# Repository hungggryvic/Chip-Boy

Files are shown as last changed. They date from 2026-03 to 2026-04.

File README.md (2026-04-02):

# Chip-Boy
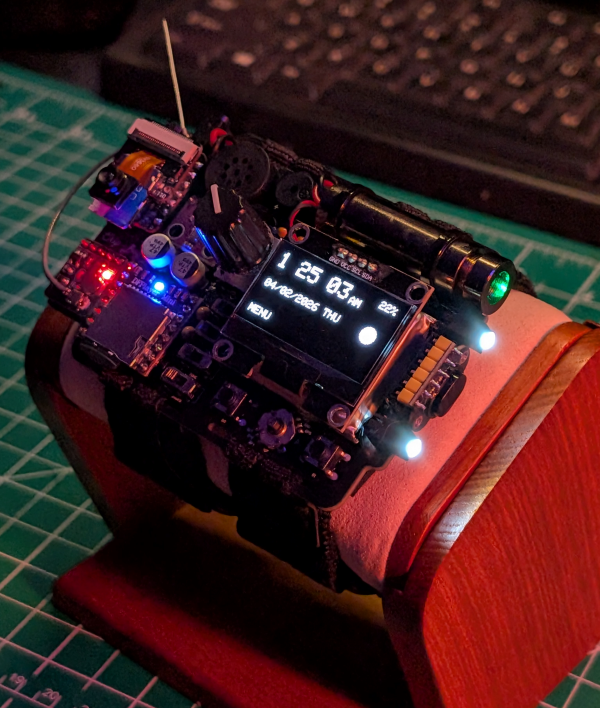
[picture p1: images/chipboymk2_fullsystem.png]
Chip-Boy Mk.2

The Chip-Boy is an ESP32-based smartwatch built on a custom PCB. It is a wrist-mounted device designed as a compact “mini computer,” focused on sensor integration, exploration, and entertainment.

The system integrates multiple sensors, including a BME280 environmental sensor, a time-of-flight distance sensor, and a BNO055 IMU for motion tracking. A 1.3" 128x64 OLED display provides a user interface, allowing navigation through menus and submenus using a combination of buttons and a rotary encoder, all operable with one hand.

The device includes an MP3 player and speaker system using a DFPlayer Mini, which reads audio files from an SD card with custom firmware and track management. It also features three white LEDs for flashlight functionality and a laser module for distance measurement and experimental use.

The ESP32-S3 Sense onboard camera and microphone enable image capture and audio recording, with files stored directly to an SD card. A GPS module provides location tracking with accuracy up to approximately 6 meters, along with automatic time and date synchronization.

Battery voltage is monitored using a voltage divider circuit connected to an ADC pin, allowing estimation of remaining battery life. The system also uses an MCP23008 I2C GPIO expander to manage inputs and control logic efficiently. A small 3V buzzer provides notifications and audio feedback. 

---

## Features

- **OLED Display Interface**  
  1.3" 128x64 OLED display with a custom menu-based UI, allowing users to navigate apps, view data, and interact with the system in real time.

- **Intuitive Input System**  
  Button-controlled navigation combined with a rotary encoder enables one-handed operation and smooth menu traversal.

- **Modular Application System**  
  Supports multiple built-in applications such as clock, navigation, compass, and media player, with the ability to expand functionality through additional modules.

- **Sensor Integration**  
  Combines multiple sensors to provide environmental, motion, and distance data for real-time feedback and analysis.

- **BNO055 IMU (Motion Tracking)**  
  Provides accelerometer, gyroscope, and magnetometer data for orientation tracking, compass functionality, and motion-based applications.

- **BME280 Environmental Sensor**  
  Measures temperature, humidity, and pressure, enabling environmental monitoring.

- **TOF400C Time-of-Flight Sensor**  
  Enables accurate distance measurement for proximity detection and navigation assistance.

- **GPS Module (Positioning & Time Sync)**  
  Provides location tracking with ~6 meter accuracy and automatic time/date calibration.

- **Camera & Microphone (ESP32-S3 Sense)**  
  Captures images and records audio, storing media directly to an SD card.

- **Audio Playback System (DFPlayer Mini)**  
  Plays MP3 files from an SD card through an onboard speaker, with custom firmware handling track selection and playback control.

- **Laser Module**  
  Used for distance indication, targeting, and experimental/measurement applications.

- **Flashlight Functionality**  
  Three high-brightness white LEDs provide illumination for low-light environments.

- **Battery Monitoring System**  
  Voltage divider connected to an ADC pin enables real-time battery level estimation.

- **Expanded I/O Control (MCP23008)**  
  I2C-based GPIO expander increases available input/output pins for buttons and peripherals.

- **Audio Feedback (Buzzer)**  
  Provides system notifications and user feedback through sound cues.

## Hardware

The Chip-Boy is built around a custom-designed embedded hardware platform integrating multiple sensors, peripherals, and user interface components onto a compact wearable PCB.

### Core System

- **ESP32-S3 (Seeed Studio XIAO)**  
  Main microcontroller responsible for system control, application execution, and peripheral interfacing. Provides Wi-Fi/Bluetooth capability, camera support, and sufficient processing power for real-time tasks.

- **Custom PCB (Altium Designer)**  
  Multi-layer board designed to integrate all components into a compact wrist-mounted form factor. Includes power routing, signal management, and modular connector interfaces.

---

### Display & User Interface

- **128×64 OLED Display (I2C)**  
  Primary user interface for rendering menus, applications, sensor data, and graphics.

- **Buttons + Rotary Encoder (via MCP23008 GPIO Expander)**  
  Enables one-handed navigation through menus and applications. The GPIO expander reduces microcontroller pin usage while supporting multiple inputs.

- **Piezo Buzzer**  
  Provides audio feedback for navigation, alerts, and system events.

---

### Sensors & Modules

- **BNO055 IMU (9-DOF)**  
  Provides orientation, acceleration, and heading data for navigation and motion-based features.

- **BME280 Environmental Sensor**  
  Measures temperature, humidity, and pressure for environmental monitoring.

- **VL53L1X Time-of-Flight Distance Sensor**  
  Enables precise distance measurement for proximity sensing and experimental applications.

- **ATGM336H GPS Module**  
  Provides real-time location data, accurate time synchronization, and navigation capabilities (~6m accuracy).

- **ESP32-S3 Camera (Sense Module)**  
  Integrated camera used for image capture and processing.

- **I2S Microphone (ESP32-S3 Sense)**  
  Enables audio recording and real-time signal capture.

---

### Audio System

- **DFPlayer Mini MP3 Module**  
  Handles audio playback from SD card storage independently of the main processor.

- **Speaker Output**  
  Provides audio output for music playback, notifications, and system feedback.

---

### Storage

- **MicroSD Card Interface**  
  Used for storing audio files, recorded data, and captured images.

---

### Power System

- **3.7V 900mAh LiPo Battery**  
  Provides portable power for the wearable device. Runtime varies based on usage. Heavy power consumption (laser, flashlight, music player) can bring the device to it's minimum operating voltage within 2.5 hours or less, while light usage and battery-saving practices can extend runtime up to 12 hours. More testing and calculations will be conducted in the near future for better analysis. 

- **Voltage Divider (ADC Monitoring Circuit)**  
  100k/100k Ohm divider allows the ESP32 to measure battery voltage and estimate remaining charge.

- **Power Switching Circuit**  
  2n7000 Mosfet switching circuit with decoupling and bulk capacitors enables safe control of system power and peripheral activation.

---

### Additional Features

- **Laser Module (MOSFET-Controlled)**  
  Used for distance assistance and experimental functionality.

- **White LEDs (Flashlight Function)**  
  Provide illumination for low-light environments.

---

### Communication Interfaces

- **I2C Bus** → Sensors, OLED display, GPIO expander  
- **SPI Bus** → SD card and high-speed peripherals  
- **UART** → DFPlayer Mini communication  
- **I2S** → Microphone audio input  
- **Camera Interface** → Native ESP32-S3 camera connection  

---

## Schematic
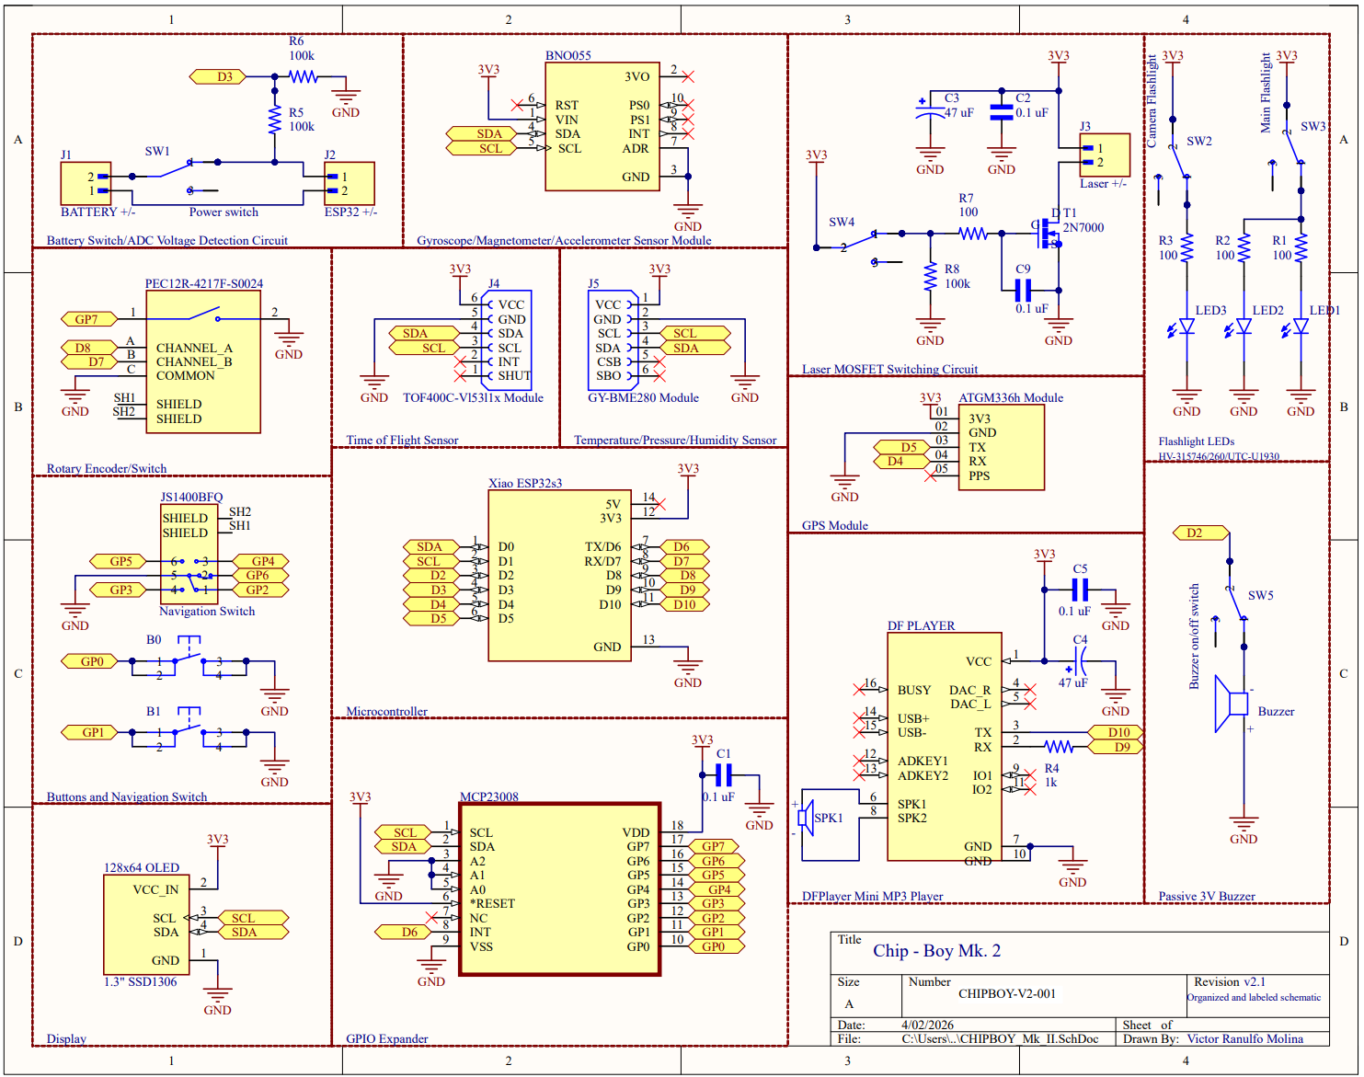
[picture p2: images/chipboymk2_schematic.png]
Chip-Boy Mk.2


## Software

The Chip-Boy firmware is developed in **C++ using the Arduino framework** on the **ESP32-S3 (Seeed Studio XIAO)**. The system is designed as a **modular embedded firmware platform** that functions similarly to a lightweight operating system, managing applications, hardware interfaces, user input, and real-time data processing.

---

### System Architecture

The firmware is structured around a **state-driven application framework**, where each feature is implemented as an independent module (`.cpp/.h` pair). A centralized control loop manages global system states such as:

- Menu navigation
- Active application context
- Display updates (`uiDirty`, `displayReady`)
- Input handling from buttons and rotary encoder

Each application operates within its own state while sharing global resources such as the OLED display, SD card, and audio system.

---

### Application Modules

The system includes multiple fully integrated applications, each with dedicated logic and UI handling:

- **Camera App**  
  Captures images using the ESP32-S3 camera module. Implements a multi-stage pipeline including grayscale frame capture, image scaling to 128×64, thresholding for OLED preview, and saving both bitmap previews and full-resolution JPEGs to SD storage.  

- **Microphone App**  
  Records audio using I2S input at 16 kHz and dynamically constructs WAV files in memory before saving to SD. Includes real-time waveform visualization and recording state management.

- **Navigation App**  
  Provides GPS-based navigation with distance and bearing calculations using the Haversine formula. Includes keypad-based coordinate entry, round-trip tracking, persistent storage using NVS (Preferences), and distance-based adaptive audio feedback. 

- **Location App**  
  Displays real-time time/date and location information with graphical overlays, including a world map rendered directly on the OLED. 

- **Radio App**  
  Manages audio playback using the DFPlayer Mini, including station-based track organization, metadata handling, shuffle functionality, and animated UI elements such as waveform rendering.  

- **Recordings App**  
  Interfaces with stored audio files on the SD card, enabling playback, track navigation, and UI animations synchronized with audio output. 

- **Battery Monitoring App**  
  Continuously samples battery voltage in the background, applies averaging and decimation to maintain long-term history, and renders a time-scaled graph of battery performance. Includes voltage-to-state-of-charge estimation using interpolation. 

---

### User Interface System

- Custom UI rendered using **Adafruit SSD1306 graphics library**
- Hierarchical menu system with app launching and exit handling
- Dynamic redraw control using flags to optimize performance
- Real-time visual elements including:
  - Graphs (battery monitoring)
  - Waveform animations (audio apps)
  - Image previews (camera)
  - Keypad interfaces (navigation input)

---

### Input Handling

- Multi-button input system managed through structured button state tracking
- Rotary encoder support with incremental position tracking
- Debouncing and edge detection for reliable user interaction
- Context-sensitive input handling depending on active application

---

### Communication & Hardware Interfaces

The firmware integrates multiple peripherals using standard embedded communication protocols:

- **I2C** → OLED display, sensors, GPIO expander  
- **SPI / SD interface** → File storage and media access  
- **I2S** → Audio recording (microphone input)  
- **UART** → DFPlayer Mini communication  
- **Camera interface** → ESP32-S3 native camera driver  

---

### Data Management

- SD card used for:
  - Audio recordings and playback
  - Image storage (BMP previews + JPEG files)
- Persistent storage using **ESP32 Preferences (NVS)** for saving navigation data and system states
- Real-time buffering for audio and sensor data processing

---

### Real-Time Operation

The system operates in a continuous loop with:
- Background tasks (battery sampling, sensor updates)
- Event-driven UI updates
- Non-blocking input handling
- Time-based scheduling using `millis()`

---

### Expandability

The firmware is designed for scalability, allowing new applications to be added easily by integrating additional modules into the menu system. Each feature is encapsulated, enabling independent development without modifying core system logic.

---

## How to Run

1. Open the project in Arduino IDE  
2. Select the ESP32-S3 board  
3. Install required libraries
4. Upload the code to the device  

---

## Project Purpose

This project was developed to demonstrate skills in:
- Embedded systems design  
- PCB design and hardware integration  
- Sensor interfacing  
- Real-time system development  

---

## Author

Victor Molina   
Electrical Engineer

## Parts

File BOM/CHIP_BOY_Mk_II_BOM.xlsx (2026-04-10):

Comment | Description | Designator | Footprint | LibRef | Quantity | Website link
1.3" SSD1306 | This is the footprint for a 0.96" oled display with the same pinout. a 1.3" SSD1306 is the the module used in tested demos and what the design is built around, its from Amazon: https://www.amazon.com/dp/B0FL1Q1ZNG?ref=ppx_yo2ov_dt_b_fed_asin_title | 128x64 OLED | MODULE_DM-OLED096-636 | DM-OLED096-636 | 1
ATGM336H | ATGM336H GPS Module GPS & BDS Dual Mode Satellite Positioning Navigator with Antenna Replacement NEO-M8N for Meshtastic GPS Arduino Available on Amazon.com. Any similar module with identical pinout and size will work. https://www.amazon.com/dp/B0DXBHCYN5?ref=ppx_yo2ov_dt_b_fed_asin_title&th=1 | ATGM336h Module | SAMTEC_MTSW-105-07-L-S-240-LL | 5 pin header | 1
SKHHANA010 | 6 x 6 x 5 mm Tactile Momentary Switch button 4 pin. Any similar push button with identical size and pinout will work., [NoValue] | B0, B1 | SW_SKHHANA010 | SKHHANA010 | 2
BNO055 | IMU sensor module by Adafruit industries Part number 2472 | BNO055 | MODULE_2472 | BNO055 | 1
3V Passive Buzzer | 3V passive buzzer two pin through hole 0.36 inch diameter | BZ1 | CUI_CMI-1295IC-0385T | Buzzer_3V | 1
0.1 uF | 0.1 uF ceramic Capacitor through hole | C1, C2, C5, C9 | CAPRB250W50L450T300H550 | 0_1uF100V_CAP_FA14X7R2A104KNU00 | 4
47 uF | EEE-TPV470XAV 47 uF Electrolytic Capacitor surface mount | C3, C4 | CAP_EEETPV470XAV | 47uF_SMD | 2
DFPLAYER | DF Player Mini by DFRobot Part Number DFR0299 | DF PLAYER | MODULE_DFR0299 | DFPLAYER | 1
BATTERY +/- | jumper pins for battery pos/neg wires. | J1 | HARWIN_M20-9990246 | 2_pin_header | 1
ESP32 +/- | jumper pins for esp32s3 pos/neg wires. | J2 | HARWIN_M20-9990246 | 2_pin_header | 1
Laser +/- | Jumper for +/- wires of laser module | J3 | HARWIN_M20-9990246 | 2_pin_header | 1
TOF400C-Vl53l1x Module | TOF400C VL53L1X Time-of-Flight (ToF) Laser Ranging Sensor Breakout 940nm ToF Distance Finder Mini Laser Distance Sensor IIC Output for Ardunio | J4 | SULLINS_PPTC061LFBN-RC | PPTC061LFBNRC | 1
GY-BME280 Module | GY-BME280 Module 6 pin i2c pressure temperature and humidity sensor | J5 | SULLINS_PPTC061LFBN-RC | PPTC061LFBNRC | 1
led_through_hole | through hole indicator LEDs Part Number HV-315746/260/UTC-U1930 | LED1, LED2, LED3 | LED_WP7113ID | led_through_hole | 3
gpio extender | MCP23008-E/P-ND by Microchip Technology GPIO expander | MCP23008 | DIP254P762X533-18 | gpio extender | 1
JS1400BFQ | JS1400BFQ 2 axis + 1 select Navigation Switch | Navigation Switch | SW_JS1400BFQ | nav switch | 1
rotary encoder | PEC12R-4217F-S0024 Rotary encoder with push button | PEC12R-4217F-S0024 | XDCR_PEC12R-4217F-S0024 | rotary encoder | 1
100 | 100 Ohm through hole resistor | R1, R2, R3, R7 | RESAD640W45L370D200 | resistor_through_hole | 4
1k | 1000 Ohm through hole resistor | R4 | RESAD640W45L370D200 | resistor_through_hole | 1
100k | 100k Ohm through hole resistor | R5, R6, R8 | RESAD640W45L370D200 | resistor_through_hole | 3
Power switch | MHSS1104 Top actuated slide switch 300 mA 60V | S1 | SW_MHSS1104 | switch top actuated | 1
Camera Flashlight | MHSS1104 Top actuated slide switch 300 mA 60V | S2 | SW_MHSS1104 | switch top actuated | 1
Main Flashlight | MHSS1104 Top actuated slide switch 300 mA 60V | S3 | SW_MHSS1104 | switch top actuated | 1
Laser switch | MHSS1104 Top actuated slide switch 300 mA 60V | S4 | SW_MHSS1104 | switch top actuated | 1
Buzzer on/off switch | MHSS1104 Top actuated slide switch 300 mA 60V | S5 | SW_MHSS1104 | switch top actuated | 1
CVS-1508 | CVS-1508 Mini 8 ohm 300 mw speaker | SPK1 | SPKR_CVS-1508 | 15mm speaker | 1
2N7000 | 2n7000 n channel 60v 200 mW Mosfet | T1 | TO92 | mosfet | 1
ESP32S3 | Xiao ESP32S3 Sense by Seeed Studio with Camera Module and microphone | Xiao ESP32s3 | MODULE_113991254 | xiao_esp32 | 1

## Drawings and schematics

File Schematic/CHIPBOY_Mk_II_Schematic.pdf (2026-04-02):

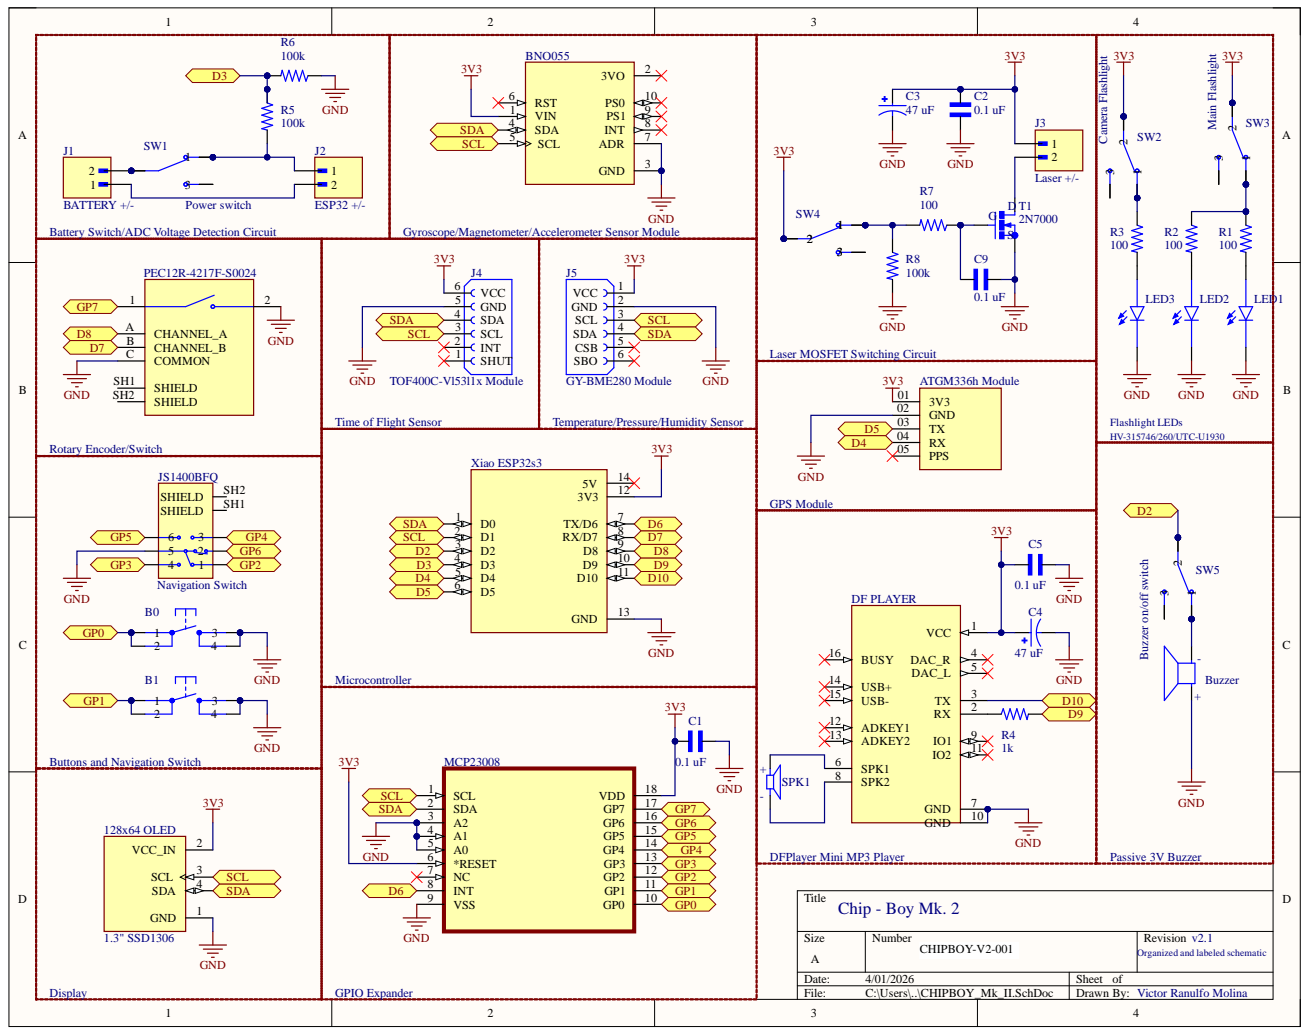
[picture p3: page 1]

Battery Switch/ADC Voltage Detection Circuit

Gyroscope/Magnetometer/Accelerometer Sensor Module

Laser MOSFET Switching Circuit

Buzzer on/off switch

Buttons and Navigation Switch

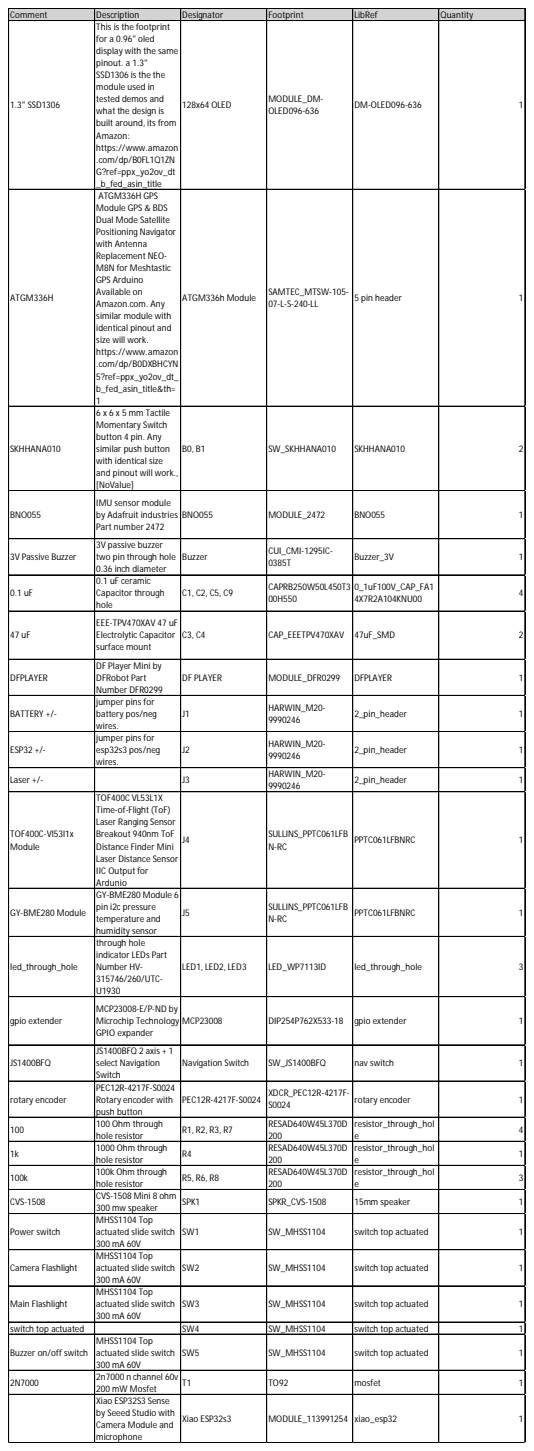
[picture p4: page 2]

Comment | Description | Designator | Footprint | LibRef | Quantity
1.3" SSD1306 | This is the footprint for a 0.96" oled display with the same pinout. a 1.3" SSD1306 is the the module used in tested demos and what the design is built around, its from Amazon: https://www.amazon.com/dp/B0FL1Q1ZNG?ref=ppx_yo2ov_dt_b_fed_asin_title | 128x64 OLED | MODULE_DM-OLED096-636 | DM-OLED096-636 | 1

ATGM336H | ATGM336H GPS Module GPS & BDS Dual Mode Satellite Positioning Navigator with Antenna Replacement NEO-M8N for Meshtastic GPS Arduino Available on Amazon.com. Any similar module with identical pinout and size will work. https://www.amazon.com/dp/B0DXBHCYN5?ref=ppx_yo2ov_dt_b_fed_asin_title&th=1 | ATGM336h Module | SAMTEC_MTSW-105-07-L-S-240-LL | 5 pin header | 1

SKHHANA010 | 6 x 6 x 5 mm Tactile Momentary Switch button 4 pin. Any similar push button with identical size and pinout will work., [NoValue] | B0, B1 | SW_SKHHANA010 | SKHHANA010 | 2

BNO055 | IMU sensor module by Adafruit industries Part number 2472 | BNO055 | MODULE_2472 | BNO055 | 1

3V Passive Buzzer | 3V passive buzzer two pin through hole 0.36 inch diameter | Buzzer | CUI_CMI-1295IC-0385T | Buzzer_3V | 1

0.1 uF | 0.1 uF ceramic Capacitor through hole | C1, C2, C5, C9 | CAPRB250W50L450T3 00H550 | 0_1uF100V_CAP_FA1 4X7R2A104KNU00 | 4

47 uF | EEE-TPV470XAV 47 uF Electrolytic Capacitor surface mount | C3, C4 | CAP_EEETPV470XAV | 47uF_SMD | 2

DFPLAYER | DF Player Mini by DFRobot Part Number DFR0299 | DF PLAYER | MODULE_DFR0299 | DFPLAYER | 1

BATTERY +/- | jumper pins for battery pos/neg wires. | J1 | HARWIN_M20-9990246 | 2_pin_header | 1

ESP32 +/- | jumper pins for esp32s3 pos/neg wires. | J2 | HARWIN_M20-9990246 | 2_pin_header | 1

Laser +/- | | J3 | HARWIN_M20-9990246 | 2_pin_header | 1

TOF400C-Vl53l1x Module | TOF400C VL53L1X Time-of-Flight (ToF) Laser Ranging Sensor Breakout 940nm ToF Distance Finder Mini Laser Distance Sensor IIC Output for Ardunio | J4 | SULLINS_PPTC061LFB N-RC | PPTC061LFBNRC | 1

GY-BME280 Module | GY-BME280 Module 6 pin i2c pressure temperature and humidity sensor | J5 | SULLINS_PPTC061LFB N-RC | PPTC061LFBNRC | 1

led_through_hole | through hole indicator LEDs Part Number HV-315746/260/UTC-U1930 | LED1, LED2, LED3 | LED_WP7113ID | led_through_hole | 3

gpio extender | MCP23008-E/P-ND by Microchip Technology GPIO expander | MCP23008 | DIP254P762X533-18 | gpio extender | 1

JS1400BFQ | JS1400BFQ 2 axis + 1 select Navigation Switch | Navigation Switch | SW_JS1400BFQ | nav switch | 1

rotary encoder | PEC12R-4217F-S0024 Rotary encoder with push button | PEC12R-4217F-S0024 | XDCR_PEC12R-4217F-S0024 | rotary encoder | 1

100 | 100 Ohm through hole resistor | R1, R2, R3, R7 | RESAD640W45L370D 200 | resistor_through_hol e | 4

1k | 1000 Ohm through hole resistor | R4 | RESAD640W45L370D 200 | resistor_through_hol e | 1

100k | 100k Ohm through hole resistor | R5, R6, R8 | RESAD640W45L370D 200 | resistor_through_hol e | 3

CVS-1508 | CVS-1508 Mini 8 ohm 300 mw speaker | SPK1 | SPKR_CVS-1508 | 15mm speaker | 1

Power switch | MHSS1104 Top actuated slide switch 300 mA 60V | SW1 | SW_MHSS1104 | switch top actuated | 1

Camera Flashlight | MHSS1104 Top actuated slide switch 300 mA 60V | SW2 | SW_MHSS1104 | switch top actuated | 1

Main Flashlight | MHSS1104 Top actuated slide switch 300 mA 60V | SW3 | SW_MHSS1104 | switch top actuated | 1

switch top actuated | | SW4 | SW_MHSS1104 | switch top actuated | 1
Buzzer on/off switch | MHSS1104 Top actuated slide switch 300 mA 60V | SW5 | SW_MHSS1104 | switch top actuated | 1

2N7000 | 2n7000 n channel 60v 200 mW Mosfet | T1 | TO92 | mosfet | 1

Xiao ESP32S3 Sense by Seeed Studio with Camera Module and microphone | Xiao ESP32s3 | MODULE_113991254 | xiao_esp32 | 1

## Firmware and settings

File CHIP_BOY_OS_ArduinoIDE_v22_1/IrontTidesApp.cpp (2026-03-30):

// ==============================
// IRON TIDES — CHIP-BOY PORT
// Display: SSD1306 (I2C D0/D1, addr 0x3C)
// Buttons: MCP23008 (BTN1/2/3 + nav switch)
// Pause: Encoder switch (debounced press event)
// ==============================

#include <Arduino.h>
#include <Wire.h>
#include <Adafruit_GFX.h>
#include <Adafruit_SSD1306.h>
#include <math.h>

#ifndef M_PI
#define M_PI 3.14159265358979323846
#endif

// ============================================================================
// WATCH OS APP WRAPPER API
// ============================================================================
static bool s_gameActive = false;
static bool s_setupRan = false;

bool ironTidesIsActive() { return s_gameActive; }
extern void gameExitToMenu();   

// Forward-declare public app API (normally in a header)
void ironTidesEnter();
void ironTidesUpdate();
void ironTidesExit();

// =====================
// Structs
// =====================

struct BtnState {
  uint8_t pin;               // MCP bit index 0..7
  bool lastRead = HIGH;      // HIGH=released (pull-ups)
  bool stable = HIGH;        // debounced stable level
  unsigned long lastChange = 0;
};

struct Ship { float x,y; float dx,dy; bool active; int lives; };

struct Bullet { float x,y; float vx,vy; bool active; bool fromEnemy; };

// =====================
// Forward Declarations
// =====================

// MCP helpers
static bool mcpWriteReg(uint8_t reg, uint8_t val);
static bool mcpReadReg(uint8_t reg, uint8_t &out);
static inline bool mcpReadBit(uint8_t bit);



// Button helpers
static void btnUpdate(BtnState &b);
static inline bool btnDown(const BtnState &b);

// Encoder switch
static bool encSwitchPressedEvent();

// Collision / gameplay helpers
static bool rectsOverlap(float ax,float ay,float aw,float ah,float bx,float by,float bw,float bh);
static bool shipWillCollide(float nx,float ny,float dx,float dy,float ox,float oy,float odx,float ody);
static bool bulletHitsShip(Bullet &b, Ship &s);
static bool bulletHitsBoss(Bullet &b);

// Drawing
static void drawShipOutline(float cx,float cy,float dx,float dy);
static void drawShipFilledArrow(float cx,float cy,float dx,float dy);
static void drawBossShip(float cx,float cy,float dx,float dy);
static void drawFrame();

// Bullets / firing
static void addBullet(float sx,float sy,float vx,float vy,bool fromEnemy);
static void fireLeft(Ship &s,unsigned long &last,bool fromEnemy);
static void fireRight(Ship &s,unsigned long &last,bool fromEnemy);
static void fireTopBurst(Ship &s,unsigned long &last,bool fromEnemy);
static void fireLeftForBoss();
static void fireRightForBoss();
static void fireTopBurstForBoss();

// UI / spawning / reset
static void showCenteredText(const char* msg,int size,int delayTime);
static void spawnEnemyAtRandomBorder(Ship &e);
static void spawnEnemiesForLevel();
static void spawnBossAtRandomBorder();
static void resetGame();

static void drawTitleWaveArches(int xShift);

#include <Arduino.h>
#include <Wire.h>
#include <Adafruit_GFX.h>
#include <Adafruit_SSD1306.h>
#include <math.h>

#ifndef M_PI
#define M_PI 3.14159265358979323846
#endif

// -------- Display ----------
#define SCREEN_WIDTH 128
#define SCREEN_HEIGHT 64
#define OLED_ADDR 0x3C

extern Adafruit_SSD1306 display;


extern bool displayReady;


static bool probeI2C(uint8_t addr) {
  Wire.beginTransmission(addr);
  return Wire.endTransmission() == 0;
}

static void ensureDisplayInit() {
  if (displayReady) return;

  // Only init if the OLED ACKs on I2C
  if (!probeI2C(OLED_ADDR)) return;

  if (display.begin(SSD1306_SWITCHCAPVCC, OLED_ADDR)) {
    displayReady = true;
    display.setTextColor(SSD1306_WHITE);
    display.setTextWrap(false);
    display.clearDisplay();
    display.display();
  }
}


// Rotary encoder switch (pause) — D6 to GND (INPUT_PULLUP)
//#define ENC_SW_PIN D6
// Encoder debouncer vars removed — main loop handles ENC_SW_PIN.


#define ENC_A_PIN D8
#define ENC_B_PIN D7

// Buzzer pin 
#ifndef BUZZER_PIN
#define BUZZER_PIN D2
#endif

// -------- MCP23008 ----------
// And mapping: BTN1->GP0, BTN2->GP6, BTN3->GP1, UP->GP4, DOWN->GP3, RIGHT->GP2, LEFT->GP5

#define MCP_ADDR   0x20
#define MCP_IODIR  0x00
#define MCP_GPIO   0x09
#define MCP_GPPU   0x06

static uint8_t g_mcp_gpio = 0xFF;
static bool g_mcp_ok = false;

static bool mcpWriteReg(uint8_t reg, uint8_t val) {
  Wire.beginTransmission(MCP_ADDR);
  Wire.write(reg);
  Wire.write(val);
  return Wire.endTransmission() == 0;
}

static bool mcpReadReg(uint8_t reg, uint8_t &out) {
  Wire.beginTransmission(MCP_ADDR);
  Wire.write(reg);
  if (Wire.endTransmission(false) != 0) return false;
  if (Wire.requestFrom((int)MCP_ADDR, 1) != 1) return false;
  out = Wire.read();
  return true;
}

//Button debounce struct 

static const unsigned long BTN_DEBOUNCE_MS = 25;

static inline bool mcpReadBit(uint8_t bit) {
  // MCP pull-ups => released=1, pressed=0
  return (g_mcp_gpio & (1u << bit)) ? HIGH : LOW;
}

static void btnUpdate(BtnState &b) {
  bool r = mcpReadBit(b.pin);
  if (r != b.lastRead) {
    b.lastRead = r;
    b.lastChange = millis();
  }
  if ((millis() - b.lastChange) >= BTN_DEBOUNCE_MS) {
    b.stable = b.lastRead;
  }
}

static inline bool btnDown(const BtnState &b) {
  return (b.stable == LOW);
}

// Encoder switch: one true event per debounced press (falling edge)
// encSwitchPressedEvent() removed — pause driven by g_gamePauseRequest.

// Button instances (MCP bits)
static BtnState b1     { .pin = 0 }; // BTN1 -> GP0
static BtnState b2     { .pin = 6 }; // BTN2 -> GP6
static BtnState b3     { .pin = 1 }; // BTN3 -> GP1
static BtnState bUp    { .pin = 4 }; // UP -> GP4
static BtnState bDown  { .pin = 3 }; // DOWN -> GP3
static BtnState bRight { .pin = 2 }; // RIGHT -> GP2
static BtnState bLeft  { .pin = 5 }; // LEFT -> GP5

// ============================================================================
// GAME CODE 
// ============================================================================


Ship enemies[3];
Ship player;
float speed = 0.35;


#define MAX_BULLETS 60
Bullet bullets[MAX_BULLETS];

int playerLives;
int enemiesDefeated = 0;
int totalEnemiesThisLevel = 3;
int currentLevel = 1;
bool gameOver = false;
bool playerWon = false;
int enemiesSpawnedThisLevel = 0;

unsigned long lastFireLeft = 0;
unsigned long lastFireRight = 0;
unsigned long lastFireTop = 0;
const unsigned long fireCooldown = 750;
const unsigned long fireCooldownTop = 750;

unsigned long enemyLastFireLeft[3] = {0,0,0};
unsigned long enemyLastFireRight[3] = {0,0,0};
unsigned long enemyLastFireTop[3] = {0,0,0};
const unsigned long enemyFireCooldown = 1500;
const unsigned long enemyFireCooldownTop = 3000;

bool paused = false;
static bool pauseOverlayDrawn = false;
static unsigned long pauseIgnoreUntilMs = 0;
static bool pauseNeedsRelease = false;

bool enemyDisintegrating = false;
int disintegratingEnemyIndex = -1;
unsigned long disintegrateStart = 0;
const unsigned long disintegrateDuration = 1000;
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

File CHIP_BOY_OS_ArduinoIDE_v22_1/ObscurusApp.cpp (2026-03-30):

// ============================================================
//  OBSCURUS — CHIP-BOY (WatchOS App Module)
//  Display: SSD1306 (I2C D0/D1, addr 0x3C)
//  Buttons: MCP23008 (BTN1/2/3 + nav switch)
//  Pause:   Encoder
//
//  Controls in game:
//    BTN2  (GP6) = JUMP (double jump)
//    BTN1  (GP0) = ATTACK / SHOOT
//    BTN3  (GP1) = CAST SPELL (once learned)
//    DOWN  (GP4) = switch to bow/switch to sword
//    LEFT  (GP2) = move left
//    RIGHT (GP5) = move right
//    ENC SW      = PAUSE
//
//  Pause menu:
//    BTN1 = PLAY (resume)
//    BTN3 = EXIT (back to games menu)
// ============================================================

#include "ObscurusApp.h"
#include <Arduino.h>
#include <Wire.h>
#include <Adafruit_GFX.h>
#include <Adafruit_SSD1306.h>
#include <math.h>

// ============================================================================
// OS APP WRAPPER STATE
// ============================================================================
static bool ob_active   = false;
static bool ob_setupRan = false;
static bool ob_inProgress = false;  // true while a game session is live (survives exit-to-menu)

bool obscurusIsActive() { return ob_active; }

extern void gameExitToMenu();
static void ob_initBoss();
static void ob_checkArrowHitBoss(int i);
static void ob_bossDeathSequence();
static void ob_shakeRoom(int steps);
static void ob_drawPlayer();
static void ob_drawSprite14(const uint8_t src[14][14], int ox, int oy, bool mirror, uint16_t color);
static void ob_drawSprite7(const uint8_t src[7][7], int ox, int oy, bool mirror, uint16_t color, bool flipV = false);
static void ob_drawRoom();
static void ob_drawTurret();
static void ob_drawBat();
static void ob_drawBullets();
static void ob_drawArrows();
static void ob_drawHearts();
static void ob_drawHUD();
static void obscurusSetup_Internal();
static void ob_doGameOver();
static void ob_drawFrame();
// ============================================================================
// SHARED HARDWARE
// ============================================================================
#define OB_SCREEN_W  128
#define OB_SCREEN_H   64
#define OB_OLED_ADDR  0x3C

extern Adafruit_SSD1306 display;
extern bool displayReady;

// ============================================================================
// MCP23008
// ============================================================================
#define OB_MCP_ADDR  0x20
#define OB_MCP_IODIR 0x00
#define OB_MCP_GPPU  0x06
#define OB_MCP_GPIO  0x09

#define OB_GP_BTN1   0
#define OB_GP_BTN3   1
#define OB_GP_LEFT   2
#define OB_GP_UP     3
#define OB_GP_DOWN   4
#define OB_GP_RIGHT  5
#define OB_GP_BTN2   6

#ifndef OB_BUZZER_PIN
#define OB_BUZZER_PIN D2
#endif

static uint8_t ob_mcpGpio  = 0xFF;
static uint8_t ob_prevGpio = 0xFF;

static bool ob_mcpWrite(uint8_t reg, uint8_t val) {
  Wire.beginTransmission(OB_MCP_ADDR);
  Wire.write(reg); Wire.write(val);
  return Wire.endTransmission() == 0;
}
static bool ob_mcpRead(uint8_t &val) {
  Wire.beginTransmission(OB_MCP_ADDR);
  Wire.write(OB_MCP_GPIO);
  if (Wire.endTransmission(false) != 0) return false;
  if (Wire.requestFrom((int)OB_MCP_ADDR, 1) != 1) return false;
  val = Wire.read();
  return true;
}
static inline bool ob_btnDown(uint8_t p)        { return !(ob_mcpGpio & (1u << p)); }
static inline bool ob_btnJustPressed(uint8_t p) { return !(ob_mcpGpio & (1u << p)) && (ob_prevGpio & (1u << p)); }

// ============================================================================
// ENCODER SWITCH
// ============================================================================
static const unsigned long OB_ENC_DEBOUNCE = 35;
static bool   ob_encSwStable    = HIGH;
static bool   ob_encSwLastRead  = HIGH;
static unsigned long ob_encSwLastChange = 0;

static bool ob_encPressed() {
  bool r = (ob_mcpGpio & (1u << 7)) ? HIGH : LOW;
  if (r != ob_encSwLastRead) { ob_encSwLastRead = r; ob_encSwLastChange = millis(); }
  if ((millis() - ob_encSwLastChange) >= OB_ENC_DEBOUNCE && r != ob_encSwStable) {
    bool fell = (ob_encSwStable == HIGH && r == LOW);
    ob_encSwStable = r;
    if (fell) return true;
  }
  return false;
}

// ============================================================================
// PAUSE STATE
// ============================================================================
static bool ob_paused             = false;
static bool ob_pauseNeedsRelease  = false;
static unsigned long ob_pauseIgnoreUntil = 0;
static bool ob_pauseBtn1WasDown   = false;
static bool ob_pauseBtn3WasDown   = false;

// ============================================================================
// TILE / MAP CONSTANTS
// ============================================================================
#define OB_TILE_SIZE  8
#define OB_MAP_COLS   16
#define OB_MAP_ROWS   8
#define OB_TILE_EMPTY 0
#define OB_TILE_SOLID 1

// ── Open-world layout (rooms 0-11 stitched into a 4×3 scrolling map) ────
// Room grid:  Rm0  Rm1  Rm2  Rm3   (grid row 0, tile rows  0-7 )
//             Rm4  Rm5  Rm6  Rm7   (grid row 1, tile rows  8-15)
//             Rm8  Rm9  Rm10w Rm11w (grid row 2, tile rows 16-23)
// Rm11w right wall = boss door → enters special rooms 10 & 11 (screen-flip)
#define OB_WORLD_TILE_COLS  64   // 4 rooms × 16 tiles
#define OB_WORLD_TILE_ROWS  24   // 3 rooms ×  8 tiles
#define OB_WORLD_PX_W       512  // 64 × 8
#define OB_WORLD_PX_H       192  // 24 × 8

// Boss door: right wall of Rm11w — 8×16 sprite (1 tile wide, 2 tiles tall)
// Sits on the floor: Rm11w wyOrig=128, tile rows 5-6 → world y 168-183.
// Sprite is drawn at world x = OB_WORLD_PX_W - 8 (last 8px column of world).
// Physics trigger fires when player touches x=OB_WORLD_PX_W while vertically
// overlapping the door gap.
#define OB_BOSS_DOOR_Y0   168   // world y of door top    (128 + 5*8)
#define OB_BOSS_DOOR_Y1   184   // world y of door bottom (128 + 7*8 = floor row)

// Camera — top-left of the 128×64 viewport in world pixels
static int16_t ob_camX = 0;
static int16_t ob_camY = 0;

// Flat world tile array built at game-start from rooms 0-9
static uint8_t ob_worldTiles[OB_WORLD_TILE_ROWS][OB_WORLD_TILE_COLS];

// true  = classic screen-flip mode for rooms 10 / 11
// false = open-world scrolling for rooms 0-9
static bool ob_inSpecialRoom = false;

// World-space position saved when entering a special room
// so we can return the player to the right spot on exit
static int16_t ob_specialReturnWorldX = 0;
static int16_t ob_specialReturnWorldY = 0;


// ============================================================================
// PHYSICS CONSTANTS
// ============================================================================
#define OB_PLAYER_W        6
#define OB_PLAYER_H        8
#define OB_GRAVITY         1
#define OB_JUMP_VY        -7
#define OB_JUMP_VY2       -6
#define OB_WALK_SPEED      2
#define OB_MAX_FALL_SPEED  6
#define OB_MAX_JUMPS       2
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

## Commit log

2026-03-29 chip boy os and schemtic altium files
    [CHIPBOY_Mk_II.GBL, CHIPBOY_Mk_II.GBO, CHIPBOY_Mk_II.GBP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]
2026-03-30 updated folder names
    [CHIPBOY_Mk_II.GBL, CHIPBOY_Mk_II.GBO, CHIPBOY_Mk_II.GBP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]
2026-04-01 Updated project tree and files
    [CHIPBOY_Mk_II.GBL, CHIPBOY_Mk_II.GBO, CHIPBOY_Mk_II.GBP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]
2026-04-02 Updated schematic with bill of materials
2026-04-02 Added schematic to README
2026-04-10 updated Radio app and CONTRIBUTING.md
    [CHIP_BOY_Mk_II_BOM.xlsx]
